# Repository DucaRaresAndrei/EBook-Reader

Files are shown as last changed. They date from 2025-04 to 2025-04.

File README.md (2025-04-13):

**Duca Andrei-Rares - 331CA**

# OpenBook - E-Book Reader

## Diagrama bloc

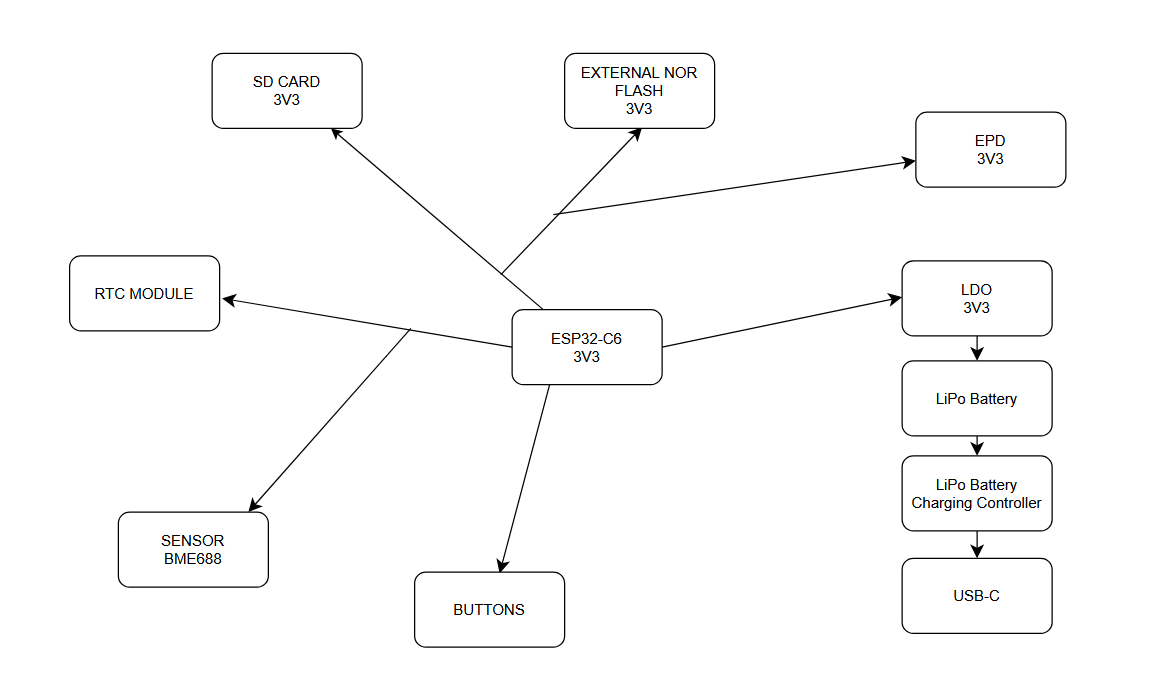
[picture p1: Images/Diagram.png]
Diagrama Bloc


## Descrierea functionalitatilor hardware

Proiectul OpenBook Reader se bazeaza pe un microcontroller ESP32-C6 care gestioneaza comunicatia si controlul mai multor componente si senzori. Sistemul este alimentat fie printr-un port USB-C, fie printr-o baterie Li-Po reincarcabila, gestionata de un modul de incarcare MCP73831. Tensiunea de 3.3V necesara majoritatii componentelor este furnizata de un regulator LDO.

### Module si componente principale:

- **ESP32-C6 (modul principal)**  
  Controleaza comunicatia cu toate modulele periferice prin protocoale SPI, I2C, UART si GPIO.

- **Modul de incarcare MCP73831 + baterie Li-Po**  
  Incarca acumulatorul si permite alimentarea portabila a dispozitivului.

- **LDO Voltage Regulator (XC6220A331MR-G)**  
  Stabilizeaza tensiunea la 3.3V pentru alimentarea componentelor sensibile.

- **E-Ink Display 1.5" (EPD)**  
  Afiseaza continutul static intr-un mod eficient energetic. Este controlat prin interfata SPI.

- **SD Card**  
  Utilizat pentru stocarea fisierelor, accesat prin SPI.

- **External NOR Flash 64MB (W25Q512JVEIQ)**  
  Memorie externa conectata prin SPI pentru stocare suplimentara.

- **RTC Module DS3231SN**  
  Asigura un ceas de timp real precis, comunicand prin I2C.

- **Sensor BME688**  
  Senzor ambiental (temperatura, umiditate, presiune, calitate aer) conectat prin I2C.

- **Butoane fizice (RESET, BOOT, CHANGE)**  
  Conectate direct la GPIO pentru interactiune manuala si control.

### Specificatii si interfete utilizate:

| Componenta | Interfata | Tensiune  | Detalii |
|---|---|---|---|
| E-Ink Display | SPI | 3.3V | 1.5", 200x200px |
| SD Card | SPI | 3.3V | Card microSD pentru stocare externa |
| External NOR Flash | SPI | 3.3V | Memorie Flash 64MB |
| RTC DS3231SN | I2C | 3.3V | Ceas cu cristal integrat |
| Senzor BME688 | I2C | 3.3V | Temperatura, presiune, gaz, umiditate |
| Butoane | GPIO | - | RESET, BOOT, CHANGE |

### Aspecte legate de consumul de energie:

E-Ink-ul si RTC-ul sunt componente cu consum foarte redus, ceea ce permite un timp indelungat de utilizare pe baterie. Comutarea modulelor periferice se face prin pinii GPIO pentru a permite dezactivarea lor in modul deep sleep. Consumul estimat in idle este de aproximativ 0.5 mA, iar in activitate de pana la 150 mA (in functie de sarcina EPD si activitatea ESP32).

## Pini ESP32-C6

| Pin ESP32-C6 | Functie | Componenta | Justificare |
|---|---|---|---|
| EN | RESET | Buton Reset | Reset hardware general pentru microcontroller |
| IO0 | INT RTC | RTC DS3231SN | Semnal de wake-up de la RTC |
| IO1 | 32KHZ | RTC DS3231SN | Iesire frecventa 32kHz din RTC |
| IO2 | MISO | SPI (Flash, SD) | Linie de date SPI pentru citire (shared) |
| IO3 | EPD_BUSY | E-Ink Display | Citire stare de ocupare a display-ului |
| IO4 | SS_SD | SD Card | Chip Select pentru cardul microSD |
| IO5 | EPD_DC | E-Ink Display | Selectie Comanda/Data pentru e-paper |
| IO6 | SCK | SPI Bus | Clock SPI comun pentru SD, Flash, EPD |
| IO7 | MOSI | SPI Bus | Linie de date SPI pentru scriere (shared) |
| IO8 | IO/BOOT | Buton Boot | Intrare in modul programare (Flash Mode) |
| IO9 | - | - | Pin neutilizat |
| IO10 | - | - | Pin neutilizat |
| IO11 | FLASH_CS | NOR Flash | Chip Select dedicat pentru memoria externa |
| IO12 | USB D- | USB-C | Linie USB pentru comunicare si alimentare |
| IO13 | USB D+ | USB-C | Linie USB pentru comunicare si alimentare |
| IO15 | IO/CHANGE | Buton CHANGE | Buton pentru schimbarea modului de afisare sau functionalitate |
| IO16 | TX (UART0) | Debug Serial | Transmitere date catre monitor serial |
| IO17 | RX (UART0) | Debug Serial | Receptie date de la monitor serial |
| IO18 | RTC_RST | RTC DS3231SN | Reset software pentru RTC |
| IO19 | I2C_PW | BME688 | Control alimentare senzor prin tranzistor |
| IO20 | EPD_3V3_C | E-Ink Display | Activare alimentare 3.3V pentru e-paper |
| IO21 | SDA | I2C (RTC, BME688) | Linia de date I2C partajata |
| IO22 | SCL | I2C (RTC, BME688) | Linia de ceas I2C partajata |
| IO23 | EPD_RST | E-Ink Display | Reset hardware pentru display |

## Bill Of Materials

| Componenta | Link de cumparare | Datasheet |
|---|---|---|
| ESP32-C6-WROOM-1-N8 | [Model](https://www.snapeda.com/parts/ESP32-C6-WROOM-1-N8/Espressif+Systems/view-part/?ref=eda) | [Datasheet](//efaidnbmnnnibpcajpcglclefindmkaj/https://www.mouser.com/catalog/specsheets/Espressif_ESP32_C6_WROOM_1%20_Datasheet_V0.1_PRELIMINARY_en.pdf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) |
| Si1308EDL-T1-GE3 | [Model](https://componentsearchengine.com/part-view/SI1308EDL-T1-GE3/Vishay) | [Datasheet](https://www.alldatasheet.com/view.jsp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) |
| KP-1608SURCK | [Model](https://www.snapeda.com/parts/KP-1608SURCK/Kingbright/view-part/?ref=search&t=LED%200603) | [Datasheet](//efaidnbmnnnibpcajpcglclefindmkaj/https://media.elv.com/file/107153_led_surck1608_data.pdf) |
| R0402 | [Model](https://componentsearchengine.com/part-view/R0402%201%25%20100%20K%20(RC0402FR-07100KL)/YAGEO) | [Datasheet](//efaidnbmnnnibpcajpcglclefindmkaj/https://www.resistor.com/assets/pdf/0402tstd.pdf) |
| DS3231SN# | [Model](https://www.snapeda.com/parts/DS3231SN%23/Analog+Devices/view-part/?ref=eda) | [Datasheet](https://www.alldatasheet.com/view.jsp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) |
| PGB1010603MR | [Model](https://www.snapeda.com/parts/PGB1010603MR/Littelfuse/view-part/?ref=eda) | [Datasheet](https://www.alldatasheet.com/view.jsp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) |
| USBLC6-2SC6Y | [Model](https://www.snapeda.com/parts/USBLC6-2SC6Y/STMicroelectronics/view-part/?ref=eda) | [Datasheet](https://www.digikey.com/en/htmldatasheets/production/1375342/0/0/1/usblc6-2sc6y) |
| USB4110-GF-A | [Model](https://componentsearchengine.com/part-view/USB4110-GF-A/GCT%20(GLOBAL%20CONNECTOR%20TECHNOLOGY)) | [Datasheet](//efaidnbmnnnibpcajpcglclefindmkaj/https://gct.co/files/drawings/usb4110.pdf) |
| CPH3225A | [Model](https://www.snapeda.com/parts/CPH3225A/Seiko+Instruments/view-part/?ref=eda) | [Datasheet](https://octopart.com/datasheet/cph3225a-seiko-25340571) |
| Adafruit | [Model](https://eu.mouser.com/ProductDetail/Adafruit/4208?qs=PzGy0jfpSMtbScLbr0L5dw%3D%3D) | [Datasheet](https://www.arrow.com/en/manufacturers/adafruit-industries/datasheets) |
| SD0805S020S1R0 | [Model](https://ro.mouser.com/ProductDetail/KYOCERA-AVX/SD0805S020S1R0?qs=jCA%252BPfw4LHbpkAoSnwrdjw%3D%3D) | [Datasheet](https://www.alldatasheet.com/view.jsp?Searchword=SD0805S&sField=2) |
| W25Q512JVEIQ | [Model](https://www.snapeda.com/parts/ESP32-C6-WROOM-1-N8/Espressif+Systems/view-part/?ref=eda) | [Datasheet](//efaidnbmnnnibpcajpcglclefindmkaj/https://www.mouser.com/datasheet/2/949/W25Q512JV_SPI_RevB_06252019_KMS-2487502.pdf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) |
| EVQPUJ02K | [Model](https://industry.panasonic.com/global/en/products/control/switch/light-touch/number/evqpuj02k) | [Datasheet](https://www.lcsc.com/datasheet/lcsc_datasheet_2201121800_PANASONIC-EVQPUJ02K_C2936858.pdf) |
| XC6220A331MR-G | [Model](https://componentsearchengine.com/part-view/XC6220A331MR-G/Torex) | [Datasheet](https://www.alldatasheet.com/view.jsp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) |
| Bobina | [Model](https://store.comet.srl.ro/Catalogue/Product/43497/) | [Datasheet](https://www.scribd.com/document/814581278/Datasheet-Bobina) |
| MAX17048G+T10 | [Model](https://www.snapeda.com/parts/MAX17048G+T10/Analog+Devices/view-part/?ref=eda) | [Datasheet](https://www.alldatasheet.com/view.jsp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) |
| SMD Solder | [Model](https://grabcad.com/library/solder-jumpers-1) | [Datasheet]() |
| BUTTON | [Model](https://industry.panasonic.com/global/en/products/control/switch/light-touch/number/evqpuj02k) | [Datasheet](https://www.lcsc.com/datasheet/lcsc_datasheet_2201121800_PANASONIC-EVQPUJ02K_C2936858.pdf) |
| BME680 | [Model](https://www.snapeda.com/parts/BME680/Bosch/view-part/?welcome=home) | [Datasheet](//efaidnbmnnnibpcajpcglclefindmkaj/https://www.bosch-sensortec.com/media/boschsensortec/downloads/datasheets/bst-bme680-ds001.pdf) |
| PFMF | [Model](https://www.mouser.co.uk/ProductDetail/EPCOS-TDK/B72520T0350K062?qs=dEfas%2FXlABIszF52uu7vrg%3D%3D) | [Datasheet](https://ro.mouser.com/c/ds/circuit-protection/thermistors/resettable-fuses-pptc/?m=Schurter&series=PFMF) |
| DMG2305UX-7 | [Model](https://componentsearchengine.com/part-view/DMG2305UX-7/Diodes%20Incorporated) | [Datasheet](//efaidnbmnnnibpcajpcglclefindmkaj/https://www.mouser.com/datasheet/2/115/DMG2305UX-266242.pdf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) |
| BD5229G-TR | [Model](https://componentsearchengine.com/part-view/BD5229G-TR/ROHM%20Semiconductor) | [Datasheet](https://www.lcsc.com/datasheet/lcsc_datasheet_2201131330_ROHM-Semicon-BD5229G-TR_C962636.pdf) |
| MCP73831T-5ACI/OT | [Model](https://www.mouser.co.uk/ProductDetail/Microchip-Technology/MCP73831T-5ACI-OT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) | [Datasheet](//efaidnbmnnnibpcajpcglclefindmkaj/https://ww1.microchip.com/downloads/en/DeviceDoc/MCP73831-Family-Data-Sheet-DS20001984H.pdf) |
| CAPACITOR | [Model](https://componentsearchengine.com/part-view/R0402%201%25%20100%20K%20(RC0402FR-07100KL)/YAGEO) | [Datasheet](//efaidnbmnnnibpcajpcglclefindmkaj/https://www.resistor.com/assets/pdf/0402tstd.pdf) |

## Etapele implementarii proiectului:

- Am realizat schematicul conform exemplului din cerinta si folosind biblioteca specificata. Am verificat cu ERC si nu am intampinat nicio eroare. Warningurile avute au fost acceptate deoarece nu reprezinta o problema pentru structura proiectului.

- Am proiectat PCb-ul, unde am respectat in clar dimensiunile date. Am pozitionat cu grija piesele, incercand sa le pozitionez ca in fisierul exemplu. Am facut rutarea, planurile de masa si am rulat cu fisierul corect de DRC. Am rezolvat erorile de air wire pe cat de mult posibil, ramanand doar una, ce am fost nevoit sa o accept.

- Am modelat piesele 3D si le-am integrat in placa. Am intampinat probleme in a gasi anumite modele 3D, ba chiar am fost nevoit sa creez singur test pad-urile.

- Am creat manual bateria si displayul, dupa masuratorile si specificatiile cerute si le-am atasat, alaturi de modelul 3d al PCB-ului, la carcasa eBook-Reader-ului.

- Am corectat erorile, iar acum proiectul poate fi complet functional.

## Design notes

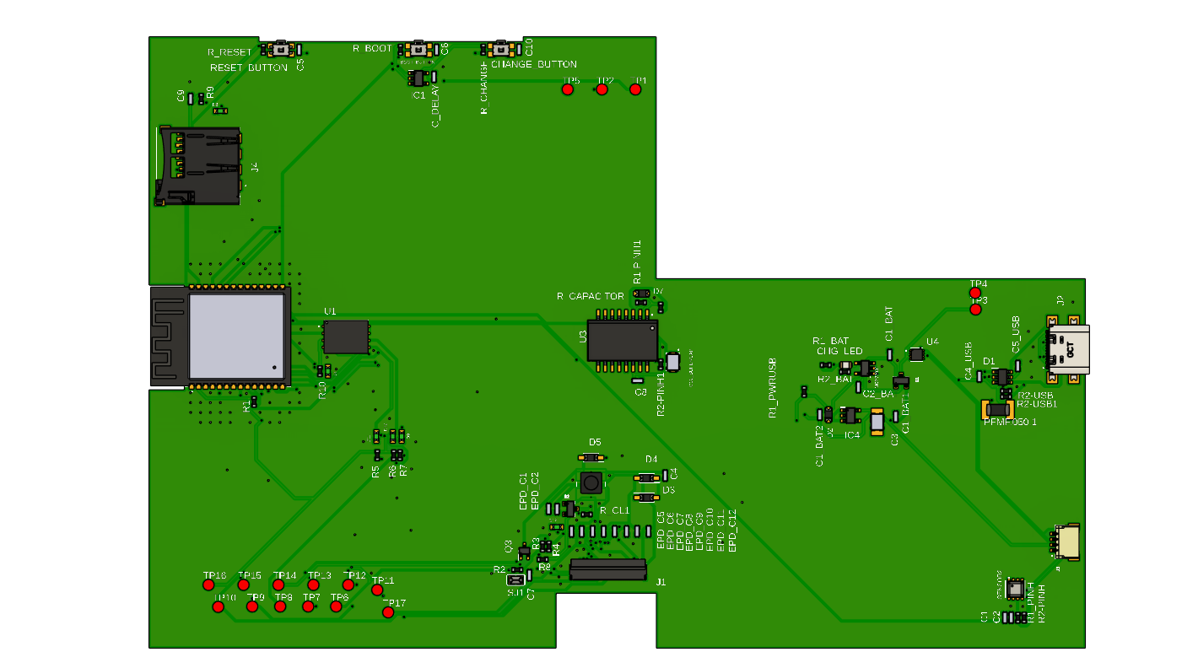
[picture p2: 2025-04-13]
Images/TopOfBoard.png

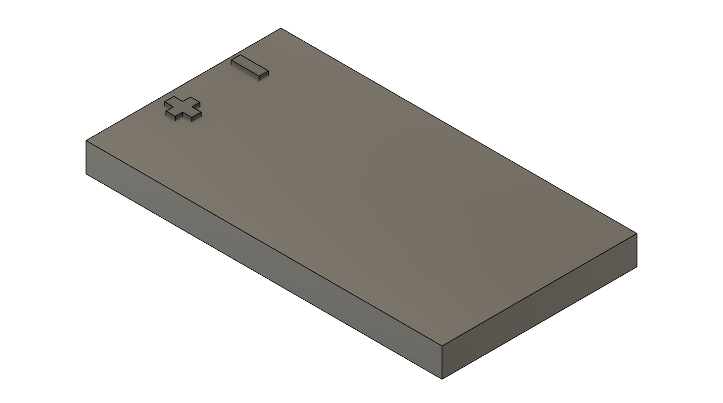
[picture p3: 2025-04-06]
Images/Battery.png

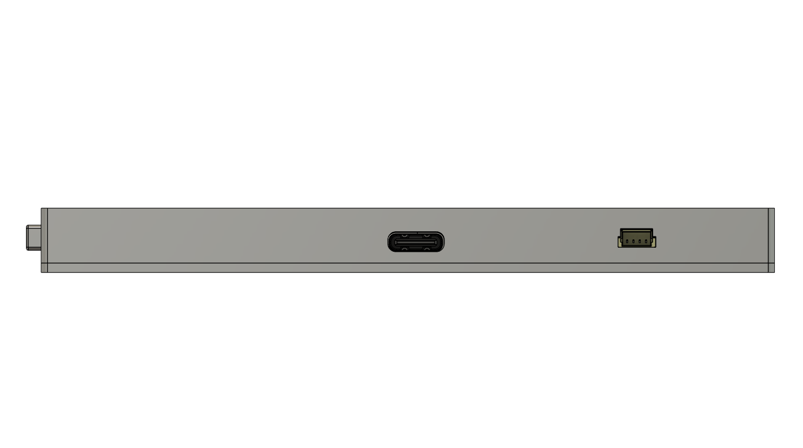
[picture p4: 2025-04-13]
Images/RightOfBook.png

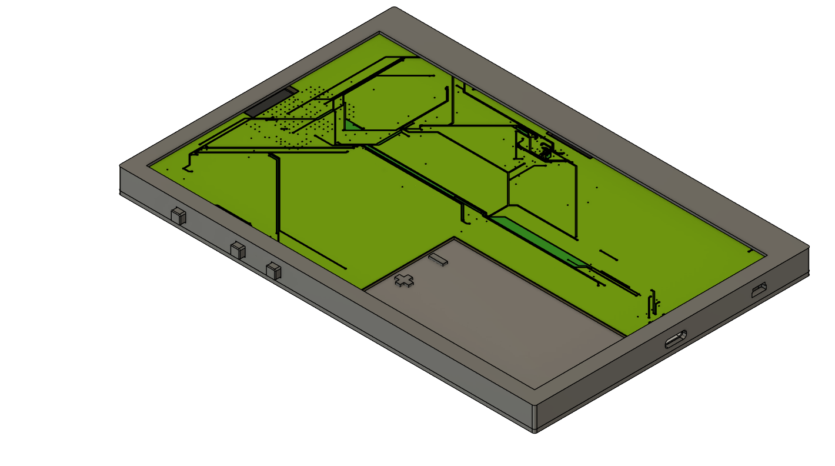
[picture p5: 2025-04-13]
Images/InsideDevice.png

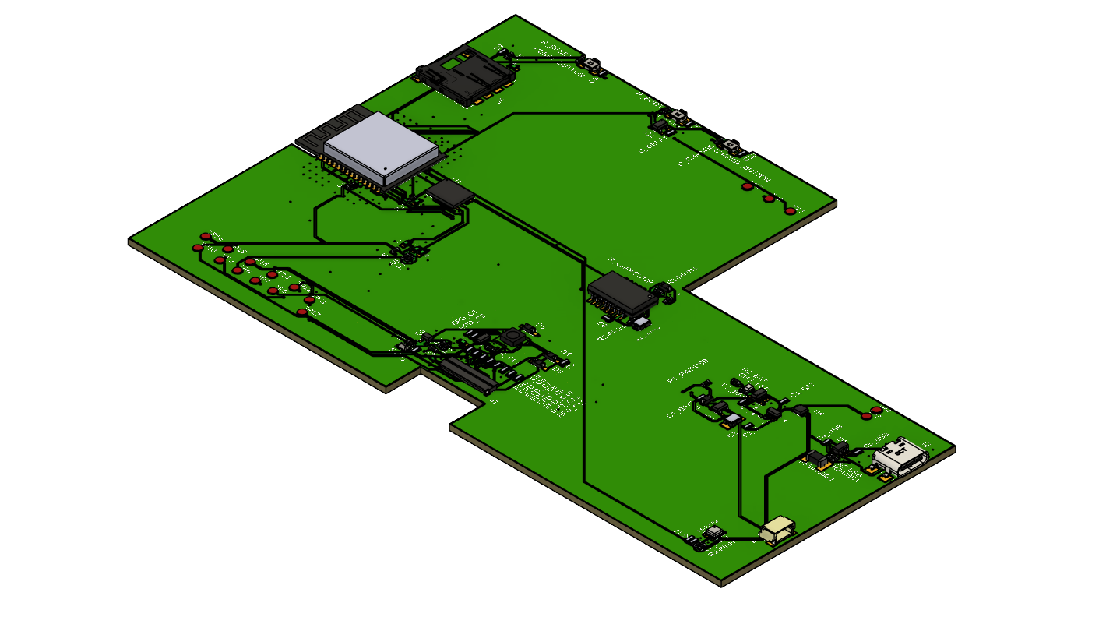
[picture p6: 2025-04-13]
Images/Board.png

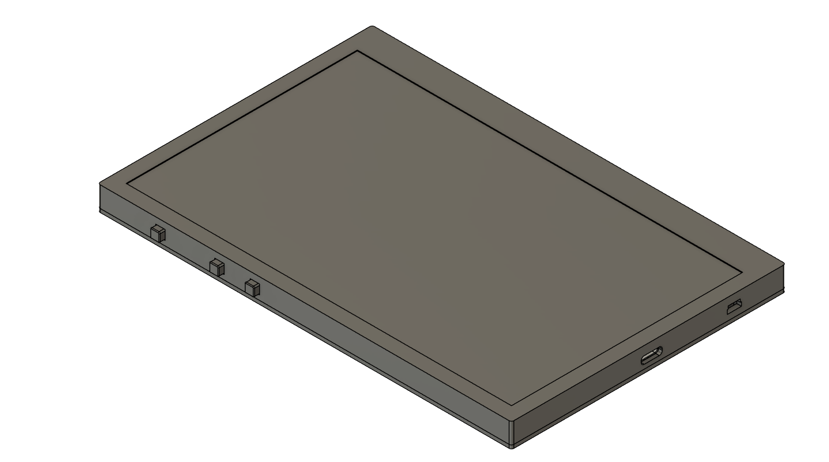
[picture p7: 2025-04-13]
Images/eBook.png

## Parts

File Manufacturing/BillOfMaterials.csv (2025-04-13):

Qty | Value | Device | Package | Parts | Description | 68UH | ARROW_PART_NUMBER | ARROW_PRICE-STOCK | AVAILABILITY | BME688 | CENTROID_NOT_SPECIFIED | CHECK_PRICES | COPYRIGHT | DATASHEET | DESCRIPTION | DIGIKEY_DESCRIPTION | Column1 | Column2 | Column3 | Column4 | Column5 | Column6 | Column7 | Column8 | Column9 | Column10 | Column11 | Column12 | Column13 | Column14 | Column15 | Column16 | Column17 | Column18 | Column19 | Column20 | Column21 | Column22 | Column23 | Column24 | Column25 | Column26 | Column27 | Column28 | Column29 | Column30 | Column31 | Column32 | Column33 | Column34 | Column35 | Column36 | Column37 | Column38 | Column39 | Column40 | Column41
1 |  | ADAFRUIT_LEDCHIP-LED0603 | ADAFRUIT_CHIP-LED0603 | CHG_LED | LED |  |  |  |  |  |  |  |  |  |  |  | DIGIKEY_PART_NUMBER | DMG2305UX-7 | HEIGHT | LEAD_FREE | MANUFACTURER_NAME | MANUFACTURER_PART_NUMBER | MF | MFR_NAME | MOUSER_PART_NUMBER | MOUSER_PRICE-STOCK | MOUSER_TESTING_PART_NUMBER | MOUSER_TESTING_PRICE-STOCK | MP | MPN | PACKAGE | POPULARITY | PREFIX | PRICE | PROD_ID | PURCHASE-URL | PWRUSB | ROHS | SD0805S020S1R0 | SNAPEDA_LINK | SPICEMODEL | SPICEPREFIX | TEMPERATURE_RANGE_HIGH | TEMPERATURE_RANGE_LOW | TP_SIGNAL_NAME | VALUE
1 |  | ESP32_WROVER_EAGLE-LTSPICE_RR0402 | ESP32_WROVER_EAGLE-LTSPICE_R0402 | R1 | RESISTOR | European symbol
1 |  | SJ | SJ | SJ1 | SMD solder JUMPER |  |  |  |  |  |  |  |  |  |  |  |  |  |  |  |  |  |  |  |  |  |  |  |  |  |  |  |  |  |  |  |  |  |  |  |  | NONE | R
1 | 0.1uF/50V | EAGLE-LTSPICE_CC0402 | EAGLE-LTSPICE_C0402 | EPD_C5 | CAPACITOR | European symbol |  |  |  |  |  |  |  |  |  |  |  |  |  |  |  |  |  |  |  |  |  |  |  |  |  | 3
1 | 0.47 | ESP32_WROVER_EAGLE-LTSPICE_RR0402 | ESP32_WROVER_EAGLE-LTSPICE_R0402 | R3 | RESISTOR | European symbol |  |  |  |  |  |  |  |  |  |  |  |  |  |  |  |  |  |  |  |  |  |  |  |  |  |  |  |  |  |  |  |  |  |  |  | NONE | C
1 | 100K | ESP32_WROVER_EAGLE-LTSPICE_RR0402 | ESP32_WROVER_EAGLE-LTSPICE_R0402 | R1_PWRUSB | RESISTOR | European symbol |  |  |  |  |  |  |  |  |  |  |  |  |  |  |  |  |  |  |  |  |  |  |  |  |  |  |  |  |  |  |  |  |  |  |  | NONE | R
8 | 100nF | EAGLE-LTSPICE_CC0402 | EAGLE-LTSPICE_C0402 | C1 | C2 | C4_USB | C6 | C8 | C9 | C10 | C_DELAY | CAPACITOR | European symbol |  |  |  |  |  |  |  |  |  |  |  |  |  |  |  |  |  |  |  |  |  |  |  |  | PWRUSB |  |  |  | NONE | R
1 | 100uF TANT | RCL_CPOL-EUCT3528 | RCL_CT3528 | C3 | POLARIZED CAPACITOR | European symbol |  |  |  |  |  |  |  |  |  |  |  |  |  |  |  |  |  |  |  |  |  |  |  |  |  |  |  |  |  |  |  |  |  |  |  |  |  |  |  |  |  |  | NONE | C
15 | 10K | ESP32_WROVER_EAGLE-LTSPICE_RR0402 | ESP32_WROVER_EAGLE-LTSPICE_R0402 | R1-PINH1 | R1_PINH | R2-PINH | R2-PINH1 | R4 | R5 | R6 | R7 | R8 | R9 | R10 | R_BOOT | R_CHANGE |  |  |  |  |  |  |  |  |  |  |  |  |  |  |  |  | 0 |  |  |  |  |  |  |  |  |  | C
1 | 10uF | EAGLE-LTSPICE_CC0402 | EAGLE-LTSPICE_C0402 | C7 | CAPACITOR | European symbol |  |  |  |  |  |  |  |  |  |  | R_CL1 | R_RESET | RESISTOR | European symbol |  |  |  |  |  |  |  |  |  |  |  |  |  |  |  |  |  |  |  |  |  |  |  |  |  |  |  |  |  |  |  |  |  |  |  | NONE | R
1 | 112A-TAAR-R03_ATTEND | 112A-TAAR-R03_ATTEND | 112ATAARR03ATTEND | J4 | Micro SD Card Socket | Push-Push Type | Top Mount | SMT | H=1.83mm | 10u |  |  |  |  |  |  |  |  |  |  |  |  |  |  |  |  |  |  |  |  |  |  |  |  |  |  |  |  |  |  |  | NONE | C
1 | 15 | ESP32_WROVER_EAGLE-LTSPICE_RR0402 | ESP32_WROVER_EAGLE-LTSPICE_R0402 | R_CAPACITOR | RESISTOR | European symbol |  |  |  |  |  |  |  |  |  |  |  |  |  | Micro SD Card Socket | Push-Push Type | Top Mount | SMT | H=1.83mm | 10u |  |  |  | 1.9mm |  | ATTEND | 112A-TAAR-R03 ATTEND
1 | 1uF | EAGLE-LTSPICE_CC0402 | EAGLE-LTSPICE_C0402 | C5 | CAPACITOR | European symbol |  |  |  |  |  |  |  |  |  |  |  |  |  |  |  |  |  |  |  |  |  |  |  |  |  |  |  |  |  |  |  |  |  |  |  | NONE | R
9 | 1uF/50V | EAGLE-LTSPICE_CC0402 | EAGLE-LTSPICE_C0402 | EPD_C1 | EPD_C2 | EPD_C6 | EPD_C7 | EPD_C8 | EPD_C9 | EPD_C10 | EPD_C11 | EPD_C12 | CAPACITOR | European symbol |  |  |  |  |  |  |  |  |  |  |  |  |  |  |  |  |  |  |  |  |  |  |  |  |  |  |  | NONE | C
1 | 02.feb | ESP32_WROVER_EAGLE-LTSPICE_RR0402 | ESP32_WROVER_EAGLE-LTSPICE_R0402 | R2 | RESISTOR | European symbol |  |  |  |  |  |  |  |  |  |  |  |  |  |  |  |  |  |  |  |  |  |  |  |  |  |  |  |  |  |  |  |  |  |  |  |  |  |  |  |  |  |  |  | NONE | C
1 | 200 | ESP32_WROVER_EAGLE-LTSPICE_RR0402 | ESP32_WROVER_EAGLE-LTSPICE_R0402 | R1_BAT | RESISTOR | European symbol |  |  |  |  |  |  |  |  |  |  |  |  |  |  |  |  |  |  |  |  |  |  |  |  |  |  |  |  |  |  |  |  |  |  |  | NONE | R
2 | 20V/4.2A/52mO/1.4W | ESP32_WROVER_SPARKFUN-DISCRETESEMI_MOSFET_PCH-DMG2305UX-7 | ESP32_WROVER_SPARKFUN-DISCRETESEMI_SOT23-3 | Q1 | Q2 | P-channel MOSFETs |  |  |  |  |  |  |  |  |  |  |  |  |  |  |  |  |  |  |  |  |  |  |  |  |  |  |  |  |  |  |  |  |  |  |  | NONE | R
1 | 2K | ESP32_WROVER_EAGLE-LTSPICE_RR0402 | ESP32_WROVER_EAGLE-LTSPICE_R0402 | R2_BAT | RESISTOR | European symbol |  |  |  |  |  |  |  |  |  |  |  |  | DMG2305UX-7 |  |  |  |  |  |  |  |  |  |  |  |  |  |  |  |  | TRAN-14388 |  |  |  |  |  |  |  |  |  |  | 20V/4.2A/52mO/1.4W
4 | 4.7uF | EAGLE-LTSPICE_CC0402 | EAGLE-LTSPICE_C0402 | C1_BAT | C1_BAT1 | C2_BAT | C5_USB | CAPACITOR | European symbol |  |  |  |  |  |  |  |  |  |  |  |  |  |  |  |  |  |  |  |  |  |  |  |  |  |  |  |  |  |  |  |  | NONE | R
1 | 4.7uF/25V | EAGLE-LTSPICE_CC0402 | EAGLE-LTSPICE_C0402 | C4 | CAPACITOR | European symbol |  |  |  |  |  |  |  |  |  |  |  |  |  |  |  |  |  |  |  |  |  |  |  |  |  |  |  |  |  |  |  |  |  |  |  |  |  |  | NONE | C
1 | 4.7uf | EAGLE-LTSPICE_CC0402 | EAGLE-LTSPICE_C0402 | C1_BAT2 | CAPACITOR | European symbol |  |  |  |  |  |  |  |  |  |  |  |  |  |  |  |  |  |  |  |  |  |  |  |  |  |  |  |  |  |  |  |  |  |  |  | NONE | C
2 | 5k1 | ESP32_WROVER_EAGLE-LTSPICE_RR0402 | ESP32_WROVER_EAGLE-LTSPICE_R0402 | R2-USB | R2-USB1 | RESISTOR | European symbol |  |  |  |  |  |  |  |  |  |  |  |  |  |  |  |  |  |  |  |  |  |  |  |  |  |  |  |  |  |  |  |  |  |  | NONE | C
1 | 744043680IND_4828-WE-TPC_WRE | 744043680IND_4828-WE-TPC_WRE | IND_4828-WE-TPC_WRE | L1 |  | 68UH |  |  |  |  |  |  | Copyright (C) 2024 Ultra Librarian. All rights reserved. |  |  |  |  |  |  |  |  |  |  |  |  |  |  |  |  |  |  |  |  |  |  |  |  |  |  |  |  |  | NONE | R
1 | BD5229G-TR | BD5229G-TR | SOT95P280X125-5N | IC1 | Voltage Detector with Adjustable Delay Time: CMOS processes are utilized to develop high precision | low current consumption CMOS reset ICs that allow arbitrary setting of the delay time. The extensive lineup includes both Nch Open Drain and CMOS output types in a wide range of detection voltages (from 2.3V to 6.0V | in 0.1V steps) | enabling selection of the ideal solution based on customer requirements. In addition | the entire series is of course both lead-free and RoHS-compliant. |  |  |  |  |  |  |  |  |  |  |  |  | 744043680 |  | Wurth Electronics
3 | BUTTON_CUSYOMV1 | BUTTON_CUSYOMV1 | MYBUTTON | BOOT_BUTTON | CHANGE_BUTTON | RESET_BUTTON |  |  |  |  |  |  |  |  |  |  |  |  | Voltage Detector with Adjustable Delay Time: CMOS processes are utilized to develop high precision | low current consumption CMOS reset ICs that allow arbitrary setting of the delay time. The extensive lineup includes both Nch Open Drain and CMOS output types in a wide range of detection voltages (from 2.3V to 6.0V | in 0.1V steps) | enabling selection of the ideal solution based on customer requirements. In addition | the entire series is of course both lead-free and RoHS-compliant. |  |  |  | 1.25mm |  | ROHM Semiconductor | BD5229G-TR |  |  | 755-BD5229G-TR | https://www.mouser.co.uk/ProductDetail/ROHM-Semiconductor/BD5229G-TR?qs=4kLU8WoGk0vvnhrrYwdszw%3D%3D
1 | CPH3225A | CPH3225A | CAPCP3225X100N | C10_SUPERCAP | Cap 0.011F 3.3V 1210 Flat Check availability |  |  |  | Not in stock |  |  | https://www.snapeda.com/parts/CPH3225A/Seiko+Instruments/view-part/?ref=eda |  |  | 11 mF (EDLC) Supercapacitor 3.3 V 1210 (3225 Metric) - -
1 | DS3231SN# | DS3231SN# | SOIC127P1032X265-16N | U3 | Real Time Clock Serial 16-Pin SOIC W T/R Check availability |  |  |  | In Stock |  |  | https://www.snapeda.com/parts/DS3231SN%23/Analog+Devices/view-part/?ref=eda |  |  | Extremely Accurate I�C-Integrated RTC/TCXO/Crystal |  |  |  |  |  |  |  | Seiko Instruments |  |  |  |  |  | CPH3225A |  | 1210 Seiko |  |  | None |  | https://www.snapeda.com/api/url_track_click_mouser/?unipart_id=562593&manufacturer=Seiko Instruments&part_name=CPH3225A&search_term=None |  |  |  | https://www.snapeda.com/parts/CPH3225A/Seiko+Instruments/view-part/?ref=snap
1 | ESP32-C6-WROOM-1-N8 | ESP32-C6-WROOM-1-N8 | XCVR_ESP32-C6-WROOM-1-N8 | U2 | Check availability |  |  |  | In Stock |  |  | https://www.snapeda.com/parts/ESP32-C6-WROOM-1-N8/Espressif+Systems/view-part/?ref=eda |  |  | Multiprotocol Modules ESP32-C6 module | Wi-Fi 6 in 2.4 GHz band |  |  |  |  |  |  | Analog Devices |  |  |  |  |  | DS3231SN# |  | SOIC-16 Maxim |  |  | None |  | https://www.snapeda.com/api/url_track_click_mouser/?unipart_id=99048&manufacturer=Analog Devices&part_name=DS3231SN#&search_term=None |  |  |  | https://www.snapeda.com/parts/DS3231SN%23/Analog+Devices/view-part/?ref=snap
1 | ESP32C6_VARISTORCN1812 | ESP32C6_VARISTORCN1812 | ESP32C6_VARISTOR_CT/CN1812 | PFMF.050.1 | VARISTOR |  |  |  |  |  |  |  |  |  |  |  | Bluetooth 5 | Zigbee 3.0 and Thread. ESP34-WROOM Compatible - ENGINEERING SAMPLE |  |  |  |  |  |  |  | Espressif Systems |  |  |  |  |  | ESP32-C6-WROOM-1-N8 |  | None |  |  | None |  |  |  |  |  | https://www.snapeda.com/parts/ESP32-C6-WROOM-1-N8/Espressif+Systems/view-part/?ref=snap
1 | ESP32_WROVER_AVX---SD0805S020S1R0_AVX_SD0805S020S1R0_0_0AVX_SD0805S020S1R0_0_0 | ESP32_WROVER_AVX---SD0805S020S1R0_AVX_SD0805S020S1R0_0_0AVX_SD0805S020S1R0_0_0 | ESP32_WROVER_AVX---SD0805S020S1R0_AVX_SD0805S020S1R0_0 | D7 | Schottky Barrier Rectifier Diode |  |  |  |  |  | No |  |  | http://datasheets.avx.com/schottky.pdf |  | DIODE SCHOTTKY 20V 1A 0805 |  |  |  |  |  |  |  |  |  |  |  |  |  |  |  | 0
1 | ESP32_WROVER_BME680_BME680 | ESP32_WROVER_BME680_BME680 | ESP32_WROVER_BME680_PSON80P300X300X100-8N | SENSOR2 | Integrated Environmental Unit |  |  |  | Unavailable | BME688 |  |  |  |  | Integrated Environmental Unit |  | 478-7800-1-ND |  |  | yes |  |  | AVX |  | 581-SD0805S020S1R0 |  |  |  |  |  | 0805 (2012 metric) |  | D |  |  |  |  | yes |  |  |  |  | +125�C | -55�C
1 | ESP32_WROVER_SPARKFUN-IC-POWER_MCP73831 | ESP32_WROVER_SPARKFUN-IC-POWER_MCP73831 | ESP32_WROVER_SPARKFUN-IC-POWER_SOT23-5 | MCP73831 | MCP73831T Li-Ion | Li-Pol Controller |  |  |  |  |  |  |  |  |  |  |  |  |  |  |  |  | Bosch Sensortec |  |  |  |  |  | BME680 |  | LGA-8 Bosch Tools |  |  | None
1 | FH34SRJ-24S-0.5SH_99_ | FH34SRJ-24S-0.5SH_99_ | FH34SRJ24S05SH99 | J1 | (0.50mm) Surface Mount | Right Angle |  |  |  |  |  |  |  |  |  | 24 Position FFC |  |  |  |  |  |  |  |  |  |  |  |  |  |  |  |  |  |  |  | IC-09995
1 | MAX17048G+T10 | MAX17048G+T10 | SON50P200X200X80-9N | U4 | Check availability |  |  |  | In Stock |  |  | https://www.snapeda.com/parts/MAX17048G+T10/Analog+Devices/view-part/?ref=eda |  |  | 3�A 1-Cell/2-Cell Fuel Gauge with ModelGauge |  | FPC Connector Contacts | (0.50mm) Surface Mount | Right Angle |  |  |  | 1.1mm |  | Hirose | FH34SRJ-24S-0.5SH(99) |  |  | 798-FH34SRJ24S05SH99 | https://www.mouser.co.uk/ProductDetail/Hirose-Connector/FH34SRJ-24S-0.5SH99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
3 | MBR0530 | MBR0530 | SOD3716X135N | D3 | D4 | D5 | ON SEMICONDUCTOR - MBR0530 - DIODE | SCHOTTKY | 0.5A | 30V | SOD-123 |  |  |  | In Stock |  |  |  |  |  |  |  | Analog Devices |  |  |  |  |  | MAX17048G+T10 |  | TDFN-8 Maxim |  |  | None |  | https://www.snapeda.com/api/url_track_click_mouser/?unipart_id=329239&manufacturer=Analog Devices&part_name=MAX17048G+T10&search_term=None |  |  |  | https://www.snapeda.com/parts/MAX17048G+T10/Analog+Devices/view-part/?ref=snap
6 | PGB1010603MR | PGB1010603MR | DIOC1608X36N | D6 | D8 | D9 | D10 | D11 | D12 | Check availability |  |  |  | In Stock |  |  |  | https://www.snapeda.com/parts/MBR0530/Onsemi/view-part/?ref=eda |  |  | Diode Schottky 30 V 500mA Surface Mount SOD-123 |  |  |  |  |  |  |  | ON Semiconductor |  |  |  |  |  | MBR0530 |  | SOD-123-2 ON Semiconductor |  |  | None |  | https://www.snapeda.com/api/url_track_click_mouser/?unipart_id=179458&manufacturer=ON Semiconductor&part_name=MBR0530&search_term=None |  |  |  | https://www.snapeda.com/parts/MBR0530/Onsemi/view-part/?ref=snap
1 | QWIIC_RIGHT_ANGLE | QWIIC_CONNECTORJS-1MM | JST04_1MM_RA | J3 | SparkFun I2C Standard Qwiic Connector |  |  |  |  |  |  |  |  |  |  |  | https://www.snapeda.com/parts/PGB1010603MR/Littelfuse/view-part/?ref=eda |  |  | 150V (Typ) Clamp - Ipp Tvs Diode Surface Mount 0603 (1608 Metric) |  |  |  |  |  |  |  | Littelfuse Inc. |  |  |  |  |  | PGB1010603MR |  | 0603 Littelfuse Inc. |  |  | None |  | https://www.snapeda.com/api/url_track_click_mouser/?unipart_id=5659453&manufacturer=Littelfuse Inc.&part_name=PGB1010603MR&search_term=None |  |  |  | https://www.snapeda.com/parts/PGB1010603MR/Littelfuse/view-part/?ref=snap
1 | SAMACSYS_PARTS_USB4110-GF-A | SAMACSYS_PARTS_USB4110-GF-A | SAMACSYS_PARTS_USB4110GFA | J2 | CONN USB 2.0 TYPE-C R/A SMT |  |  |  |  |  |  |  |  |  | CONN USB 2.0 TYPE-C R/A SMT |  |  |  |  |  |  |  |  |  |  |  |  |  |  |  |  |  |  |  | CONN-13694 |  |  |  |  |  |  |  |  |  |  | QWIIC_RIGHT_ANGLE
1 | SD0805S020S1R0 | ESP32_WROVER_AVX---SD0805S020S1R0_AVX_SD0805S020S1R0_0_0AVX_SD0805S020S1R0_0_0 | ESP32_WROVER_AVX---SD0805S020S1R0_AVX_SD0805S020S1R0_0 | D2 | Schottky Barrier Rectifier Diode |  |  |  |  |  | No |  |  | http://datasheets.avx.com/schottky.pdf |  | DIODE SCHOTTKY 20V 1A 0805 |  |  | 3.26mm |  | GCT (GLOBAL CONNECTOR TECHNOLOGY) | USB4110-GF-A |  |  | 640-USB4110-GF-A | https://www.mouser.co.uk/ProductDetail/GCT/USB4110-GF-A?qs=KUoIvG%2F9IlYiZvIXQjyJeA%3D%3D
1 | SI1308EDL-T1-GE3 | SI1308EDL-T1-GE3 | SOT65P210X110-3N | Q3 | MOSFET N-Ch 30V 1.5A TrenchFET SC70 Vishay Si1308EDL-T1-GE3 N-channel MOSFET Transistor | 1.5 A | 30 V | 3-Pin SC-70 |  |  |  | In Stock |  |  | https://www.snapeda.com/parts/SI1308EDL-T1-GE3/Vishay+Siliconix/view-part/?ref=eda |  | 478-7800-1-ND |  |  | yes |  |  | AVX |  | 581-SD0805S020S1R0 |  |  |  |  |  | 0805 (2012 metric) |  | D |  |  |  |  | yes | SD0805S020S1R0 |  |  |  | +125�C | -55�C
17 | TPTP20R | TPTP20R | TP20R | TP1 | TP2 | TP3 | TP4 | TP5 | TP6 | TP7 | TP8 | TP9 | TP10 | TP11 | TP12 | TP13 |  | Si1308EDL-T1-GE3 N-channel MOSFET Transistor | 1.5 A | 30 V | 3-Pin SC-70 | Siliconix / Vishay SI1308EDL-T1-GE3 |  |  |  |  |  |  |  | Vishay Siliconix |  |  |  |  |  | SI1308EDL-T1-GE3 |  | SOT-323 Vishay Semiconductor |  |  | None |  | https://www.snapeda.com/api/url_track_click_mouser/?unipart_id=274603&manufacturer=Vishay Siliconix&part_name=SI1308EDL-T1-GE3&search_term=None |  |  |  | https://www.snapeda.com/parts/SI1308EDL-T1-GE3/Vishay+Siliconix/view-part/?ref=snap
1 | USBLC6-2SC6Y | USBLC6-2SC6Y | SOT95P280X145-6N | D1 | Low Cap. ESD Protection Auto SOT-23-6 STMicroelectronics USBLC6-2SC6Y | Dual Uni-Directional TVS Diode Array | 6-Pin SOT-23 |  |  |  | In Stock |  |  | https://www.snapeda.com/parts/USBLC6-2SC6Y/STMicroelectronics/view-part/?ref=eda |  |  | TP14 | TP15 | TP16 | TP17 | Test pad |  |  |  |  |  |  |  |  |  |  |  |  |  |  |  |  |  |  |  |  |  |  |  |  |  |  | 2
1 | W25Q512JVEIQ | W25Q512JVEIQ | SON127P600X800X80-9N | U1 | Check availability |  |  |  | In Stock |  |  | https://www.snapeda.com/parts/W25Q512JVEIQ/Winbond+Electronics/view-part/?ref=eda |  |  | FLASH - NOR Memory IC 512Mb (64M x 8) SPI - Quad I/O 133 MHz 8-WSON (8x6) |  | 17V Clamp 5A (8/20�s) Ipp Tvs Diode Surface Mount SOT-23-6 |  |  |  |  |  |  |  | STMicroelectronics |  |  |  |  |  | USBLC6-2SC6Y |  | SOT-23-6 STMicroelectronics |  |  | None |  |  |  |  |  | https://www.snapeda.com/parts/USBLC6-2SC6Y/STMicroelectronics/view-part/?ref=snap
1 | XC6220A331MR-G | XC6220A331MR-G | SOT95P280X120-5N | IC4 | LDO Voltage Regulators |  |  |  |  |  |  |  |  |  | LDO Voltage Regulators |  |  |  |  |  |  |  | Winbond Electronics |  |  |  |  |  | W25Q512JVEIQ |  | Package |  |  | None |  |  |  |  |  | https://www.snapeda.com/parts/W25Q512JVEIQ/Winbond+Electronics/view-part/?ref=snap
 |  |  |  |  |  |  |  |  |  |  |  |  |  |  |  |  |  |  | 1.2mm |  | Torex | XC6220A331MR-G |  |  | 865-XC6220A331MR-G | https://www.mouser.co.uk/ProductDetail/Torex-Semiconductor/XC6220A331MR-G?qs=AsjdqWjXhJ8ZSWznL1J0gg%3D%3D

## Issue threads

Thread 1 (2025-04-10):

Routing

AndrewC3870, 2025-04-10:
⛔ Problems:

- [x] The wires do not meet the thickness requirement; all wires are 1.27 mm thick.

- [x] Presence of an air-wire.

- [x] The ground layer is not properly made; there are multiple wires carrying ground signal instead of a single ground plane.

- [x] Lack of via stitching around the ESP-32 module.

- [x] The ground layers, both on the top and bottom, have areas that are still isolated.

✅ Possible Solution:

- [x] Change wire thickness: 0.3 mm for power routes and 0.15 mm for data.

- [x] Route the air-wire.

- [x] Add vias with ground signal.

AndrewC3870, 2025-04-10:
⚠️ Some Images with the problems:

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

Closed 2025-04-13.

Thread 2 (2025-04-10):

PCB

AndrewC3870, 2025-04-10:
⛔ Problems:

- [x] Labels are not properly placed; some are placed over components, others outside the PCB.

- [x] Values are shown alongside component names.

- [x] The PCB thickness is not within specification.

✅ Possible Solution:

- [x] Adjust label positions and remove component values from the silkscreen.

- [x] Modify layer thicknesses.

AndrewC3870, 2025-04-10:
⚠️ Some Images with the problems:

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

Closed 2025-04-13.

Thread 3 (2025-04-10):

Schematic and Manufactured

AndrewC3870, 2025-04-10:
⛔ Problems:

- [x] Labels are overlapping component

- [x] The bill-of-materials and pick-and-place files are not exported properly, making them unreadable.

✅ Solution:

- [x] Adjust label positions.

- [x] Properly export the files.

AndrewC3870, 2025-04-10:
⚠️ Some Images with the problems:

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

Closed 2025-04-13.

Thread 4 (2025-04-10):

PCB and 3D components fitting

AndrewC3870, 2025-04-10:
⛔ Problems:

- [x] The PCB is not correctly aligned within the enclosure.

- [x] Components such as the Type-C connector, Qwiic, and SD card slot are not aligned with the holes in the enclosure.

✅ Possible Solution:

- [x] The PCB must be aligned (using the Align tool) with the lid body.

- [x] Modify either the enclosure or the position of the components.

AndrewC3870, 2025-04-10:
⚠️ Some Images with the problems:

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

Closed 2025-04-13.

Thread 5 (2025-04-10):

Screen design

AndrewC3870, 2025-04-10:
⛔ Problems:

- [x] The 3D design of the screen does not match the dimensions specified in the datasheet

- [x] The screen is incorrectly positioned, causing interference with the enclosure.

✅ Possible Solution:

- [x] The 3D model must be modified and correctly placed in the enclosure.

Closed 2025-04-13.

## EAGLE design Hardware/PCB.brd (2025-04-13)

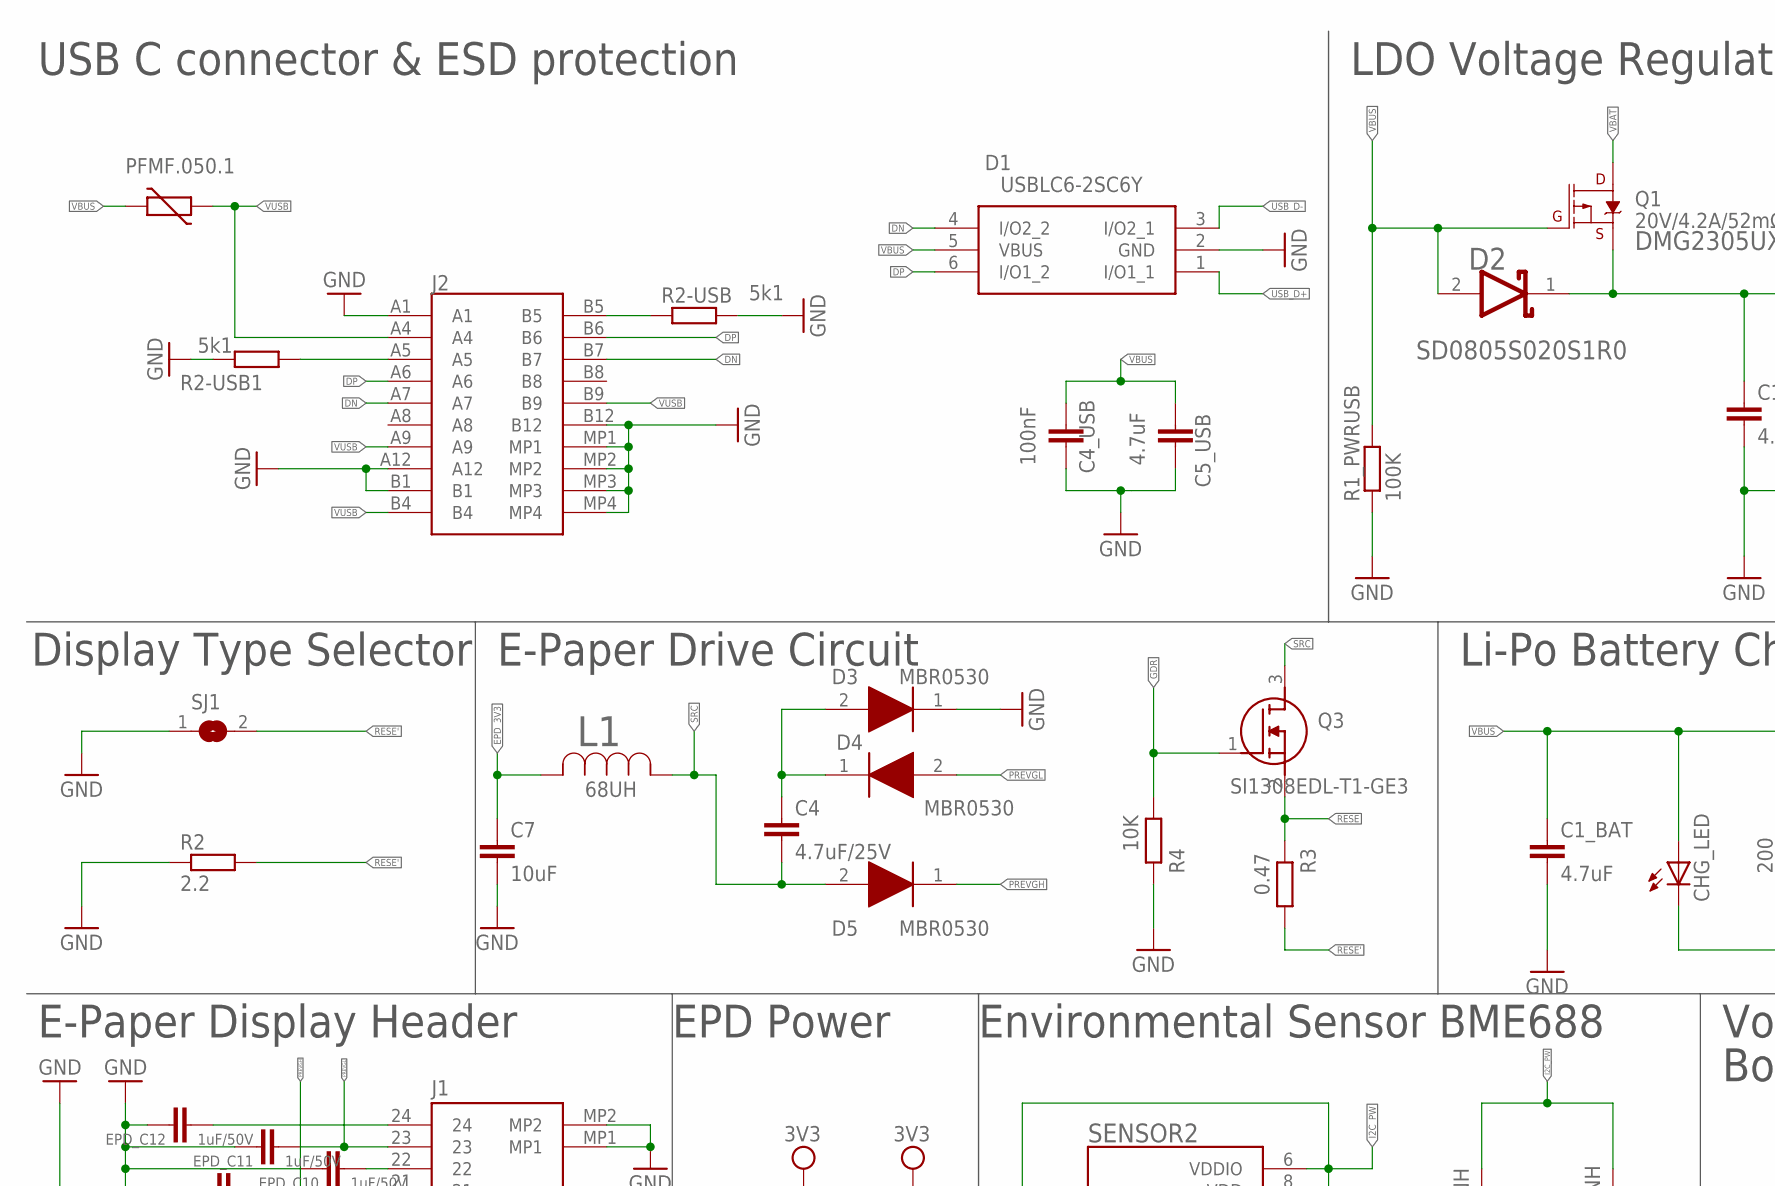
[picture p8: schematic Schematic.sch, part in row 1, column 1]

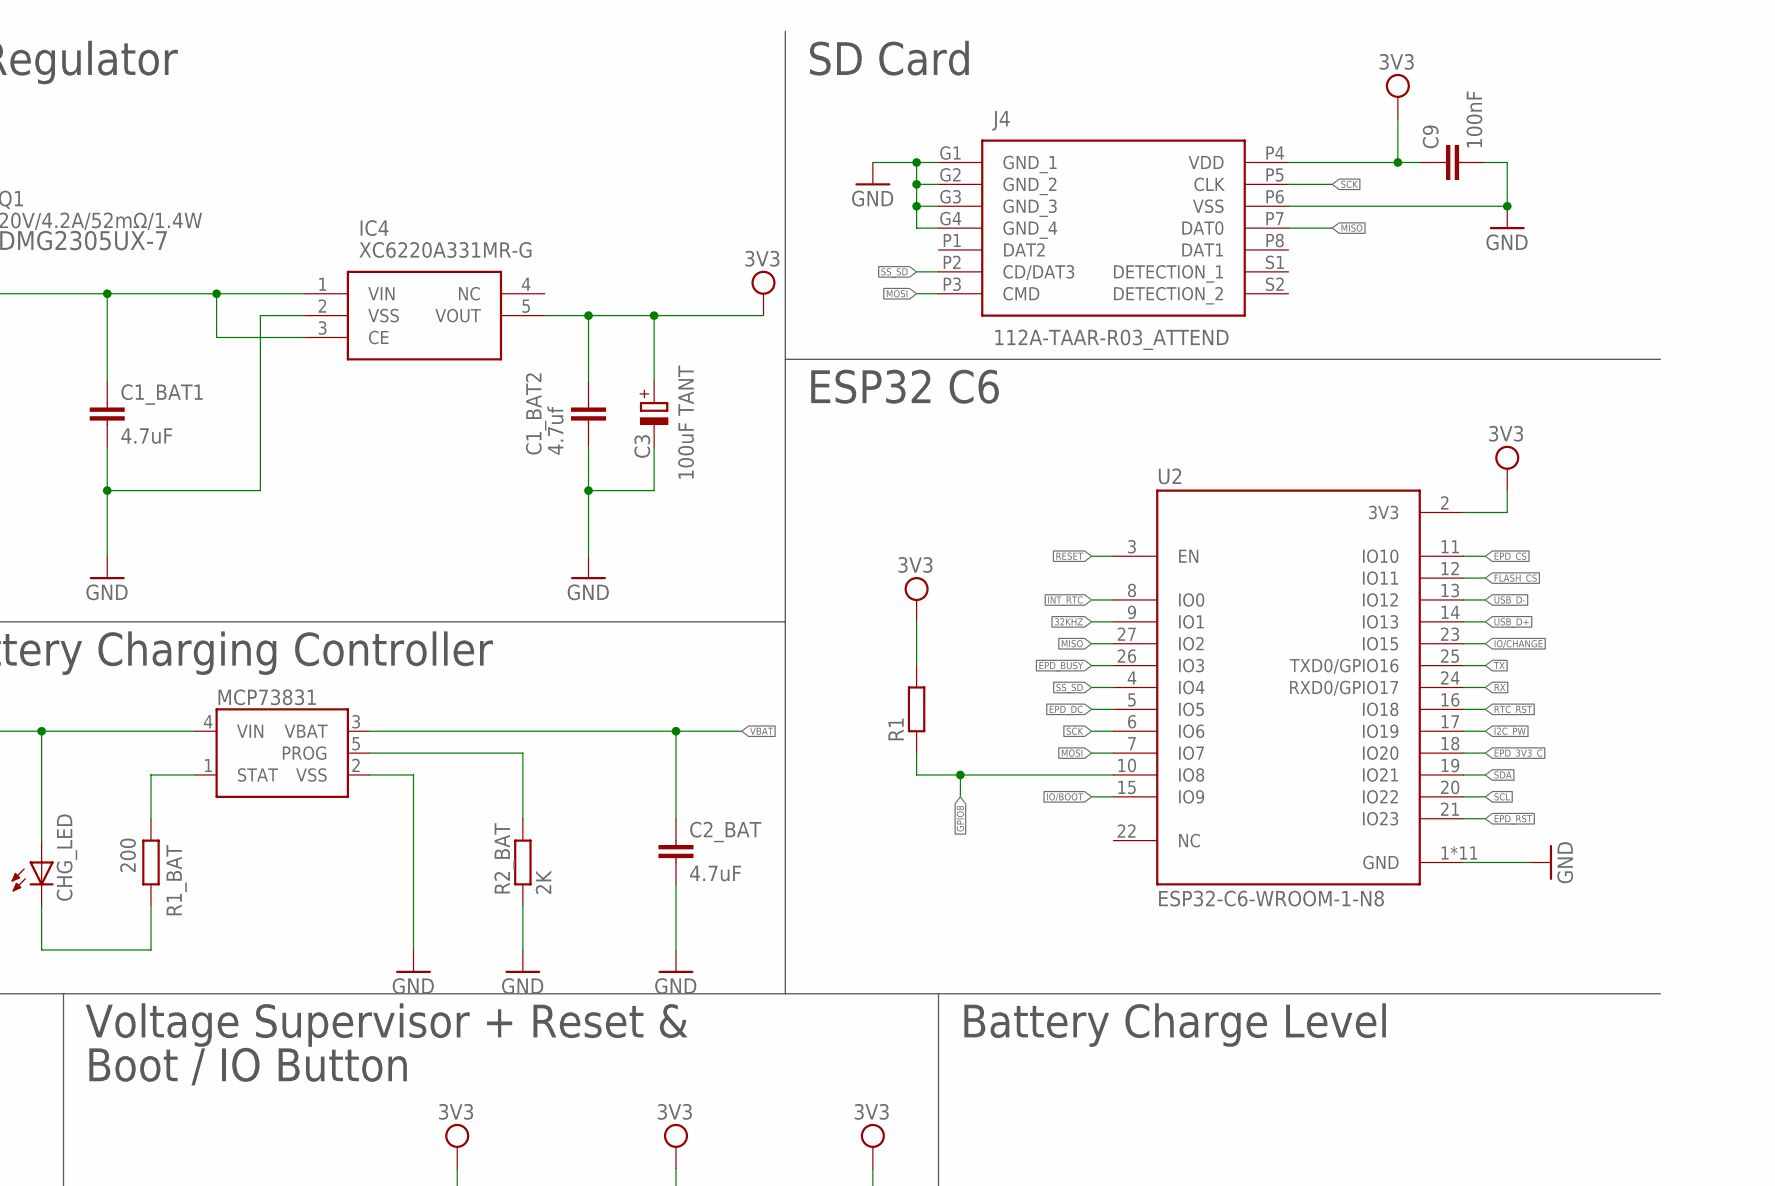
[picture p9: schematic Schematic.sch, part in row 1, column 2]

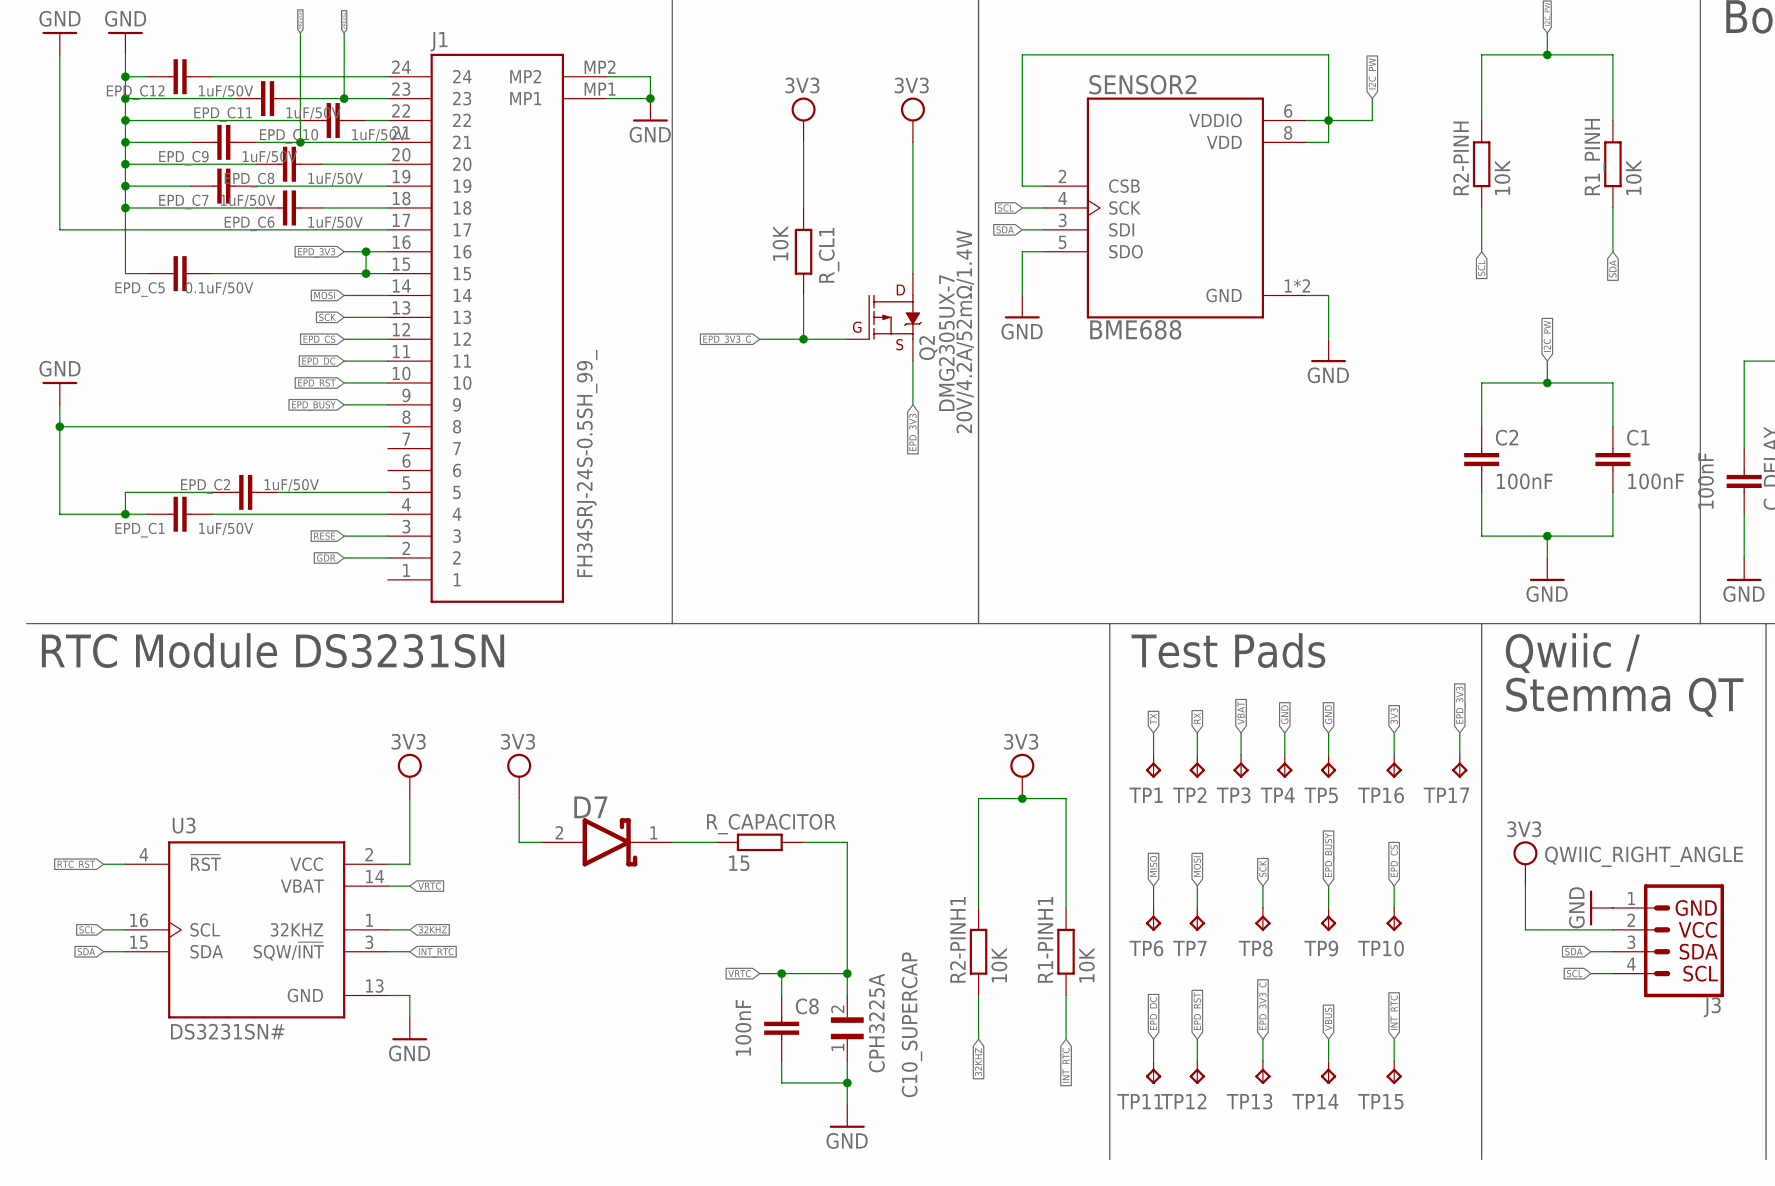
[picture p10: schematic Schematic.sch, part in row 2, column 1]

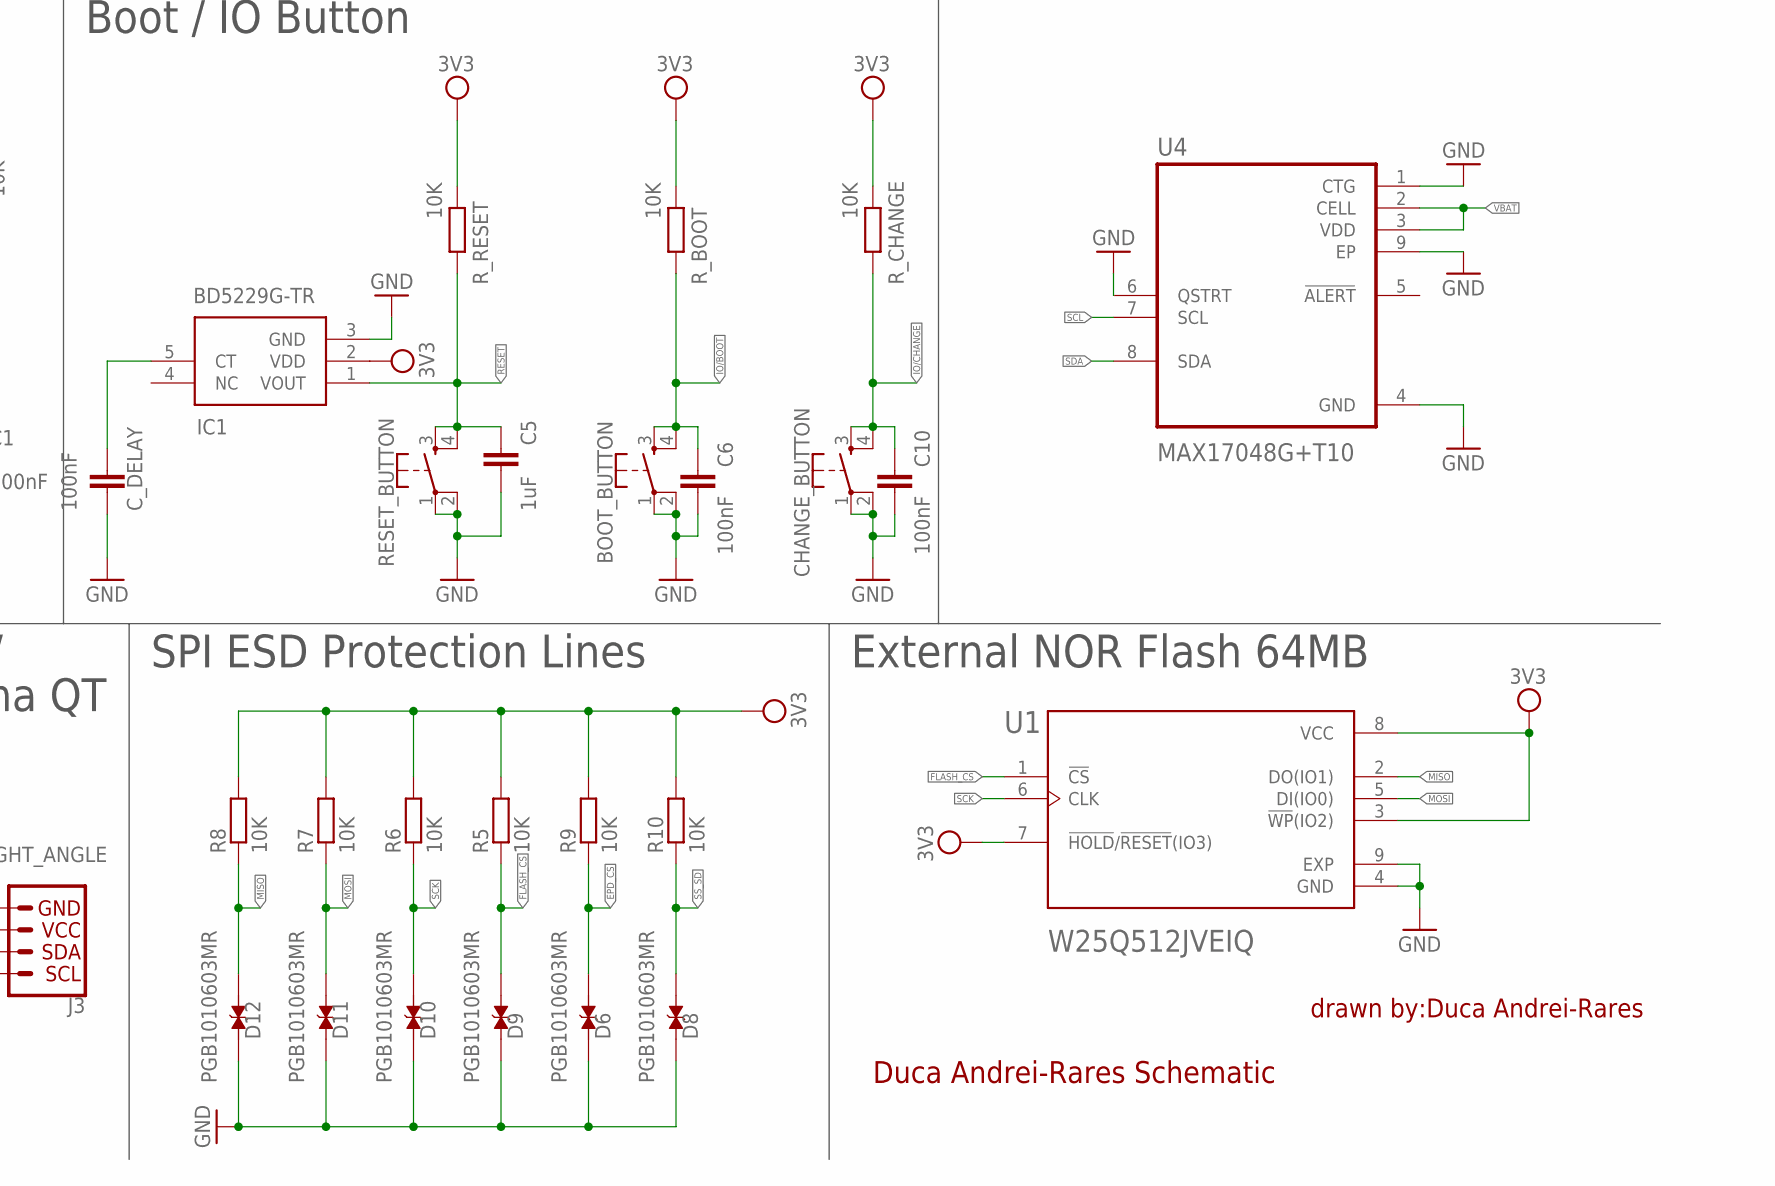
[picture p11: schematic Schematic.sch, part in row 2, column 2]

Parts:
BOOT_BUTTON: BUTTON_CUSYOMV1; MYBUTTON
C1, C2, C4_USB, C6, C8, C9, C10: 100nF; EAGLE-LTSPICE_C0402
C1_BAT, C1_BAT1, C2_BAT, C5_USB: 4.7uF; EAGLE-LTSPICE_C0402
C1_BAT2: 4.7uf; EAGLE-LTSPICE_C0402
C3: 100uF TANT; RCL_CT3528
C4: 4.7uF/25V; EAGLE-LTSPICE_C0402
C5: 1uF; EAGLE-LTSPICE_C0402
C7: 10uF; EAGLE-LTSPICE_C0402
C10_SUPERCAP: CPH3225A; CAPCP3225X100N
CHANGE_BUTTON: BUTTON_CUSYOMV1; MYBUTTON
CHG_LED: ADAFRUIT_LEDCHIP-LED0603; ADAFRUIT_CHIP-LED0603
C_DELAY: 100nF; EAGLE-LTSPICE_C0402
D1: USBLC6-2SC6Y; SOT95P280X145-6N
D2: SD0805S020S1R0; ESP32_WROVER_AVX---SD0805S020S1R0_AVX_SD0805S020S1R0_0
D3, D4, D5: MBR0530; SOD3716X135N
D6, D8, D9, D10, D11, D12: PGB1010603MR; DIOC1608X36N
D7: ESP32_WROVER_AVX---SD0805S020S1R0_AVX_SD0805S020S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; ESP32_WROVER_AVX---SD0805S020S1R0_AVX_SD0805S020S1R0_0
EPD_C1, EPD_C2, EPD_C6, EPD_C7, EPD_C8, EPD_C9, EPD_C10, EPD_C11, EPD_C12: 1uF/50V; EAGLE-LTSPICE_C0402
EPD_C5: 0.1uF/50V; EAGLE-LTSPICE_C0402
IC1: BD5229G-TR; SOT95P280X125-5N
IC4: XC6220A331MR-G; SOT95P280X120-5N
J1: FH34SRJ-24S-0.5SH_99_; FH34SRJ24S05SH99
J2: SAMACSYS_PARTS_USB4110-GF-A; SAMACSYS_PARTS_USB4110GFA
J3: QWIIC_RIGHT_ANGLE; JST04_1MM_RA
J4: 112A-TAAR-R03_ATTEND; 112ATAARR03ATTEND
L1: 744043680IND_4828-WE-TPC_WRE; IND_4828-WE-TPC_WRE
MCP73831: ESP32_WROVER_SPARKFUN-IC-POWER_MCP73831; ESP32_WROVER_SPARKFUN-IC-POWER_SOT23-5
PFMF.050.1: ESP32C6_VARISTORCN1812; ESP32C6_VARISTOR_CT/CN1812
Q1, Q2: 20V/4.2A/52mΩ/1.4W; ESP32_WROVER_SPARKFUN-DISCRETESEMI_SOT23-3
Q3: SI1308EDL-T1-GE3; SOT65P210X110-3N
R1: ESP32_WROVER_EAGLE-LTSPICE_RR0402; ESP32_WROVER_EAGLE-LTSPICE_R0402
R1-PINH1, R1_PINH, R2-PINH, R2-PINH1, R4, R5, R6, R7, R8, R9, R10: 10K; ESP32_WROVER_EAGLE-LTSPICE_R0402
R1_BAT: 200; ESP32_WROVER_EAGLE-LTSPICE_R0402
R1_PWRUSB: 100K; ESP32_WROVER_EAGLE-LTSPICE_R0402
R2: 2.2; ESP32_WROVER_EAGLE-LTSPICE_R0402
R2-USB, R2-USB1: 5k1; ESP32_WROVER_EAGLE-LTSPICE_R0402
R2_BAT: 2K; ESP32_WROVER_EAGLE-LTSPICE_R0402
R3: 0.47; ESP32_WROVER_EAGLE-LTSPICE_R0402
RESET_BUTTON: BUTTON_CUSYOMV1; MYBUTTON
R_BOOT: 10K; ESP32_WROVER_EAGLE-LTSPICE_R0402
R_CAPACITOR: 15; ESP32_WROVER_EAGLE-LTSPICE_R0402
R_CHANGE: 10K; ESP32_WROVER_EAGLE-LTSPICE_R0402
R_CL1: 10K; ESP32_WROVER_EAGLE-LTSPICE_R0402
R_RESET: 10K; ESP32_WROVER_EAGLE-LTSPICE_R0402
SENSOR2: ESP32_WROVER_BME680_BME680; ESP32_WROVER_BME680_PSON80P300X300X100-8N
SJ1: SJ
TP1, TP2, TP3, TP4, TP5, TP6, TP7, TP8, TP9, TP10, TP11, TP12, TP13, TP14, TP15, TP16, TP17: TPTP20R; TP20R
U1: W25Q512JVEIQ; SON127P600X800X80-9N
U2: ESP32-C6-WROOM-1-N8; XCVR_ESP32-C6-WROOM-1-N8
U3: DS3231SN#; SOIC127P1032X265-16N
U4: MAX17048G+T10; SON50P200X200X80-9N

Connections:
3V3: C1_BAT2.1, C3.+, C9.1, D7.2 (ANODE), IC1.2 (VDD), IC4.5 (VOUT), J3.2, J4.P4 (VDD), Q2.3 (D), R1.2, R1-PINH1.2, R2-PINH1.2, R5.2, R6.2, R7.2, R8.2, R9.2, R10.2, R_BOOT.2, R_CHANGE.2, R_CL1.2, R_RESET.2, TP16.TP, U1.3 (!WP!(IO2)), U1.7 (!HOLD!/!RESET!(IO3)), U1.8 (VCC), U2.2 (3V3), U3.2 (VCC)
32KHZ: R2-PINH1.1, U2.9 (IO1), U3.1 (32KHZ)
DN: D1.4 (I/O2_2), J2.A7, J2.B7
DP: D1.6 (I/O1_2), J2.A6, J2.B6
EPD_3V3: C7.1, EPD_C5.2, J1.15, J1.16, L1.2, Q2.2 (S), TP17.TP
EPD_3V3_C: Q2.1 (G), R_CL1.1, TP13.TP, U2.18 (IO20)
EPD_BUSY: J1.9, TP9.TP, U2.26 (IO3)
EPD_CS: D6.2, J1.12, R9.1, TP10.TP, U2.11 (IO10)
EPD_DC: J1.11, TP11.TP, U2.5 (IO5)
EPD_RST: J1.10, TP12.TP, U2.21 (IO23)
FLASH_CS: D9.2, R5.1, U1.1 (!CS), U2.12 (IO11)
GDR: J1.2, Q3.1 (G), R4.2
GND: BOOT_BUTTON.1, BOOT_BUTTON.2, C1.2, C1_BAT.2, C1_BAT1.2, C1_BAT2.2, C2.2, C2_BAT.2, C3.-, C4_USB.2, C5.2, C5_USB.2, C6.2, C7.2, C8.2, C9.2, C10.2, C10_SUPERCAP.1, CHANGE_BUTTON.1, CHANGE_BUTTON.2, C_DELAY.2, D1.2 (GND), D3.1 (K), D6.1, D8.1, D9.1, D10.1, D11.1, D12.1, EPD_C1.1, EPD_C2.1, EPD_C5.1, EPD_C6.1, EPD_C7.1, EPD_C8.1, EPD_C9.1, EPD_C10.1, EPD_C11.1, EPD_C12.1, IC1.3 (GND), IC4.2 (VSS), J1.8, J1.17, J1.MP1, J1.MP2, J2.A1, J2.A12, J2.B1, J2.B12, J2.MP1, J2.MP2, J2.MP3, J2.MP4, J3.1, J4.G1 (GND_1), J4.G2 (GND_2), J4.G3 (GND_3), J4.G4 (GND_4), J4.P6 (VSS), MCP73831.2 (VSS), R1_PWRUSB.1, R2.1, R2-USB.2, R2-USB1.1, R2_BAT.1, R4.1, RESET_BUTTON.1, RESET_BUTTON.2, SENSOR2.1 (GND), SENSOR2.5 (SDO), SENSOR2.7 (GND), SJ1.1, TP4.TP, TP5.TP, U1.4 (GND), U1.9 (EXP), U2.1 (GND), U2.28 (GND), U2.29_1 (GND), U2.29_2 (GND), U2.29_3 (GND), U2.29_4 (GND), U2.29_5 (GND), U2.29_6 (GND), U2.29_7 (GND), U2.29_8 (GND), U2.29_9 (GND), U3.13 (GND), U4.1 (CTG), U4.4 (GND), U4.6 (QSTRT), U4.9 (EP)
GPIO8: R1.1, U2.10 (IO8)
I2C_PW: C1.1, C2.1, R1_PINH.2, R2-PINH.2, SENSOR2.2 (CSB), SENSOR2.6 (VDDIO), SENSOR2.8 (VDD), U2.17 (IO19)
INT_RTC: R1-PINH1.1, TP15.TP, U2.8 (IO0), U3.3 (SQW/!INT)
IO/BOOT: BOOT_BUTTON.3, BOOT_BUTTON.4, C6.1, R_BOOT.1, U2.15 (IO9)
IO/CHANGE: C10.1, CHANGE_BUTTON.3, CHANGE_BUTTON.4, R_CHANGE.1, U2.23 (IO15)
MISO: D12.2, J4.P7 (DAT0), R8.1, TP6.TP, U1.2 (DO(IO1)), U2.27 (IO2)
MOSI: D11.2, J1.14, J4.P3 (CMD), R7.1, TP7.TP, U1.5 (DI(IO0)), U2.7 (IO7)
unnamed: J2.B5, R2-USB.1
unnamed: C1_BAT1.1, D2.1 (CATHODE), IC4.1 (VIN), IC4.3 (CE), Q1.2 (S)
unnamed: CHG_LED.C, R1_BAT.1
unnamed: MCP73831.5 (PROG), R2_BAT.2
unnamed: C4.1, D3.2 (A), D4.1 (K)
unnamed: J2.A5, R2-USB1.2
unnamed: EPD_C1.2, J1.4
unnamed: MCP73831.1 (STAT), R1_BAT.2
unnamed: EPD_C2.2, J1.5
unnamed: C_DELAY.1, IC1.5 (CT)
unnamed: D7.1 (CATHODE), R_CAPACITOR.1
unnamed: EPD_C12.2, J1.24
unnamed: EPD_C10.2, J1.22
unnamed: EPD_C8.2, J1.20
unnamed: EPD_C7.2, J1.19
unnamed: EPD_C6.2, J1.18
PREVGH: D5.1 (K), EPD_C9.2, J1.21
PREVGL: D4.2 (A), EPD_C11.2, J1.23
RESE: J1.3, Q3.2 (S), R3.2
RESE': R2.2, R3.1, SJ1.2
RESET: C5.1, IC1.1 (VOUT), RESET_BUTTON.3, RESET_BUTTON.4, R_RESET.1, U2.3 (EN)
RTC_RST: U2.16 (IO18), U3.4 (!RST)
RX: TP2.TP, U2.24 (RXD0/GPIO17)
SCK: D10.2, J1.13, J4.P5 (CLK), R6.1, TP8.TP, U1.6 (CLK), U2.6 (IO6)
SCL: J3.4, R2-PINH.1, SENSOR2.4 (SCK), U2.20 (IO22), U3.16 (SCL), U4.7 (SCL)
SDA: J3.3, R1_PINH.1, SENSOR2.3 (SDI), U2.19 (IO21), U3.15 (SDA), U4.8 (SDA)
SRC: C4.2, D5.2 (A), L1.1, Q3.3 (D)
SS_SD: D8.2, J4.P2 (CD/DAT3), R10.1, U2.4 (IO4)
TX: TP1.TP, U2.25 (TXD0/GPIO16)
USB_D+: D1.1 (I/O1_1), U2.14 (IO13)
USB_D-: D1.3 (I/O2_1), U2.13 (IO12)
VBAT: C2_BAT.1, MCP73831.3 (VBAT), Q1.3 (D), TP3.TP, U4.2 (CELL), U4.3 (VDD)
VBUS: C1_BAT.1, C4_USB.1, C5_USB.1, CHG_LED.A, D1.5 (VBUS), D2.2 (ANODE), MCP73831.4 (VIN), PFMF.050.1.2, Q1.1 (G), R1_PWRUSB.2, TP14.TP
VRTC: C8.1, C10_SUPERCAP.2, R_CAPACITOR.2, U3.14 (VBAT)
VUSB: J2.A4, J2.A9, J2.B4, J2.B9, PFMF.050.1.1

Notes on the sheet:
LDO Voltage Regulator
USB C connector & ESD protection
SD Card
Display Type Selector
E-Paper Drive Circuit
Li-Po Battery Charging Controller
ESP32 C6
Duca Andrei-Rares Schematic
drawn by:Duca Andrei-Rares
E-Paper Display Header
EPD Power
Environmental Sensor BME688
Voltage Supervisor + Reset &
Boot / IO Button
Battery Charge Level
RTC Module DS3231SN
Test Pads
Qwiic /
Stemma QT
SPI ESD Protection Lines
External NOR Flash 64MB

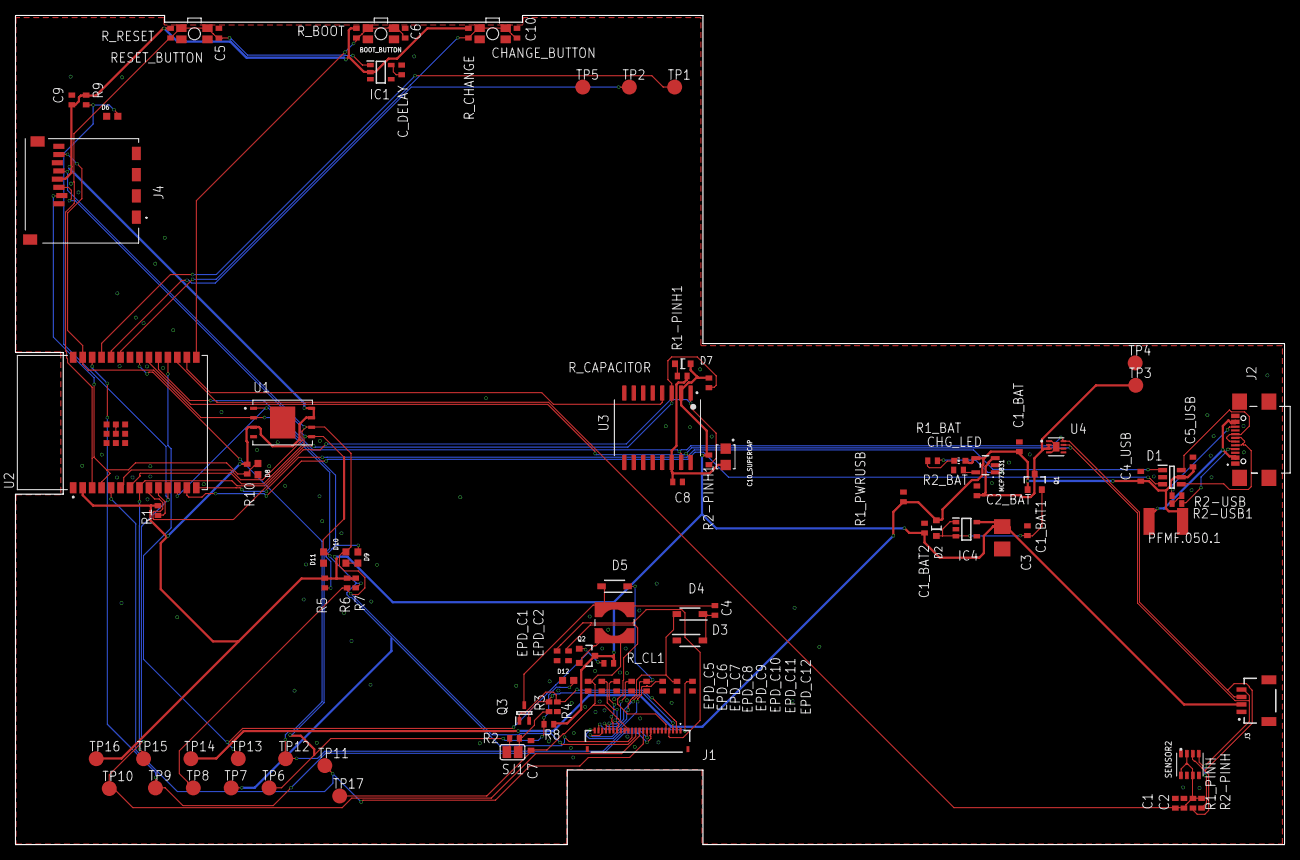
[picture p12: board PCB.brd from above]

Board: 2 copper layers, 170.2 x 111.2 mm, 103 parts (0 on the bottom side), 55 nets.

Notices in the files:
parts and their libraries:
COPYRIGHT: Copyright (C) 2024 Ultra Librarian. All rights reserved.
